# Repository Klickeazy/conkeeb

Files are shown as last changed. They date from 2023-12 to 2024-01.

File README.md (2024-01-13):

# Conkeeb - Split Keyboard

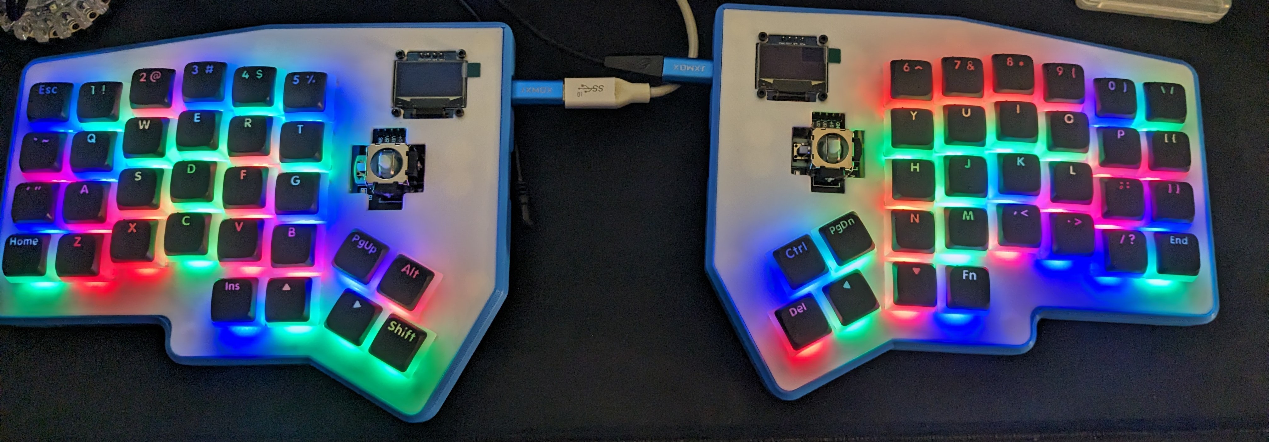
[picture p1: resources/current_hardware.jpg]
current keyboard


## Design and Fabrication
- Modified layout from ErgoDox on [KLE](http://www.keyboard-layout-editor.com/#/)
- Switch-plate template generated on [SwillKB](http://builder.swillkb.com/)
- CAD done on OnShape
- Printed on a modified Ender3Pro using a 0.6mm nozzle in PLA

## Bill of Materials
- 2 x Adafruit [NeoKey 5x6 Ortho Snap-Apart Mechanical Key Switches w/ NeoPixel - For MX Compatible Switches](https://www.adafruit.com/product/5157)
- 60 x MX socket compatible switches : Using [Gateron KS-9 RGB](https://a.co/d/2FaNAoF) for LEDs
- 50 x 1u keycaps compatible to switch stems : [Pudding Style XDA](https://a.co/d/bYV5bW5) for LEDs
- 2 x Joystick with breakout board [WMYCONGCONG Game Joystick](https://a.co/d/7XcAHXY)
- 2 x Display units [Hosyond 0.96 Inch OLED](https://a.co/d/dcp77Un)
- 2 x [USB-A breakout](https://a.co/d/6CouvCj) + 1 [USB-A Male to Male cable](https://a.co/d/9nUPYLn) : to connect the two halves of the keyboard - need 4 lines for UART, could look at alternate TRRS or USB-C connector choices
- 2 x [RPi-Pico](https://www.raspberrypi.com/products/raspberry-pi-pico/) for each of the halves - there are some spare GPIO pins - could add more hardware like an encoder or use a smaller one by sacrificing the joystick or display unit

- Fasteners **per KB half**
    - 4-6 x M3 6mm(H)x5mm(OD) heat-set inserts and 6mm socket-heads for the case and switch plate - holes dimensioned to allow for socket heads to sink into the base
    - 2 x M3 4mm (H)x5mm(OD) heat-set inserts and 4mm socket-heads for the USB-A breakout board
    - 2 x M2 4mm(H)x3.5mm(OD) heat-set inserts and 6mm screws for the Pico
    - 4 x M2 4mm socket-heads and nuts for the display unit - these screw heads are visible - pick whatever you think looks the best
    - optional :  3 x 2mm(H)x6mm(D) magnets for the foot and base

- [3D Printed parts](stl)
    - 1 each of switchplate and base L & R
    - optional foot L & R
    - Approximately 100g per base, 40g per switchplate and foot - tested with 0.6mm nozzle, 0.32mm layer height 25% adaptive cubic infill

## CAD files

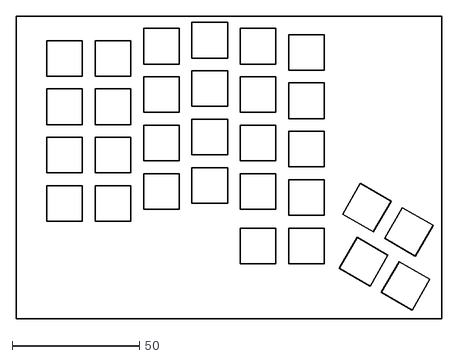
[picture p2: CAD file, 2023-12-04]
layout/V3/plate_gen.dxf
167.5 x 119.2

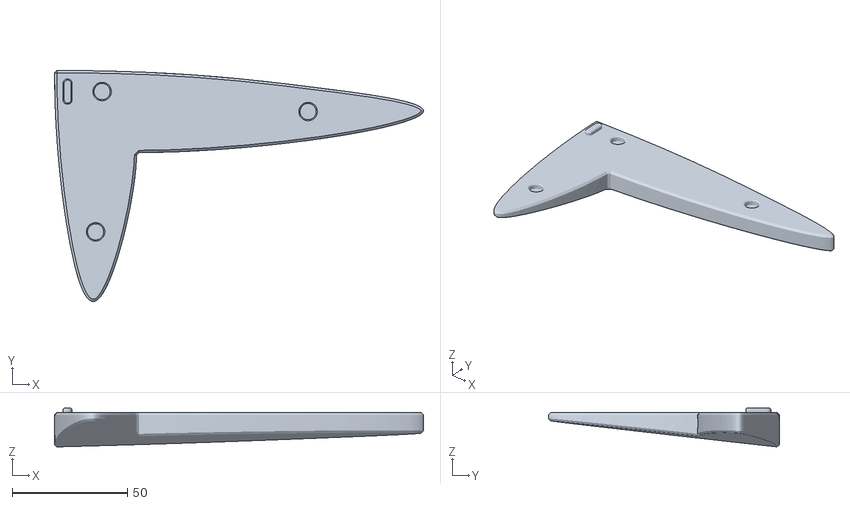
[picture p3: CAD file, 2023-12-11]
stl/FootR.stl
160.0 x 100.2 x 16.9

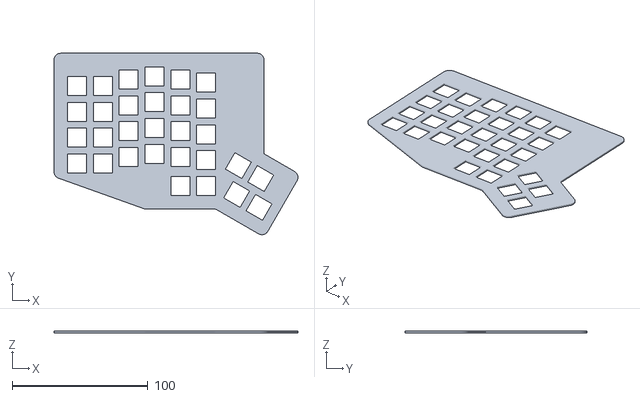
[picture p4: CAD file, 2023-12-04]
layout/V3/KeyPlateV3.stl
180.0 x 133.9 x 1.28

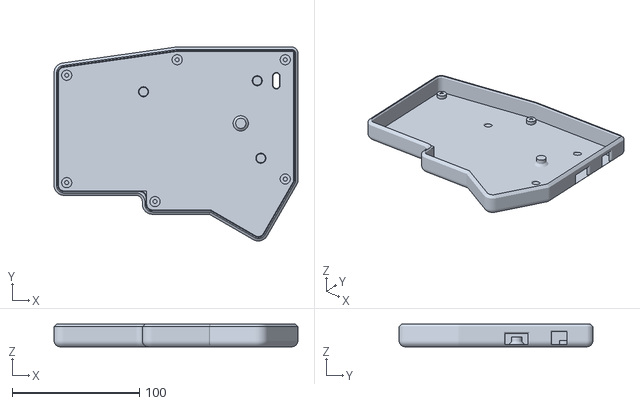
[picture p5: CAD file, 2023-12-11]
stl/BaseL.stl
191.6 x 152.3 x 17.8

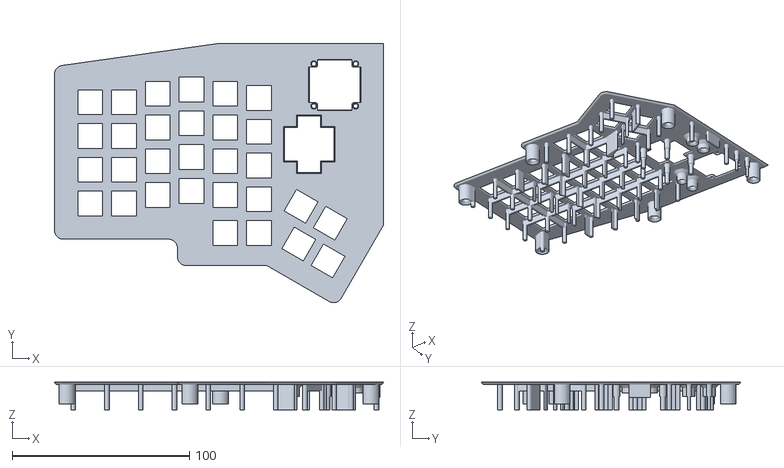
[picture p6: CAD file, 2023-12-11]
stl/SwitchPlateL.stl
185.6 x 146.3 x 15.8

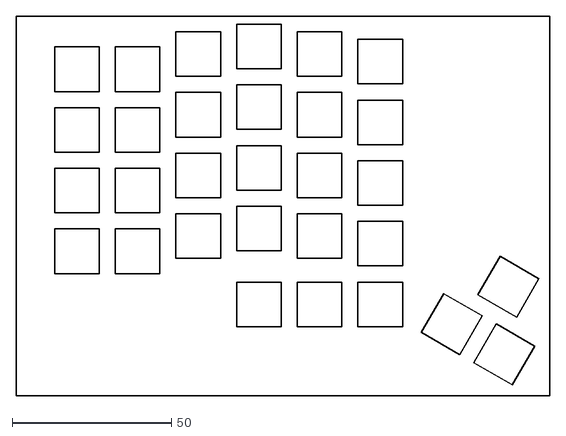
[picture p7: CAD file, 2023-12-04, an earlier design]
layout/V2/switch_plate.dxf
167.5 x 119.2

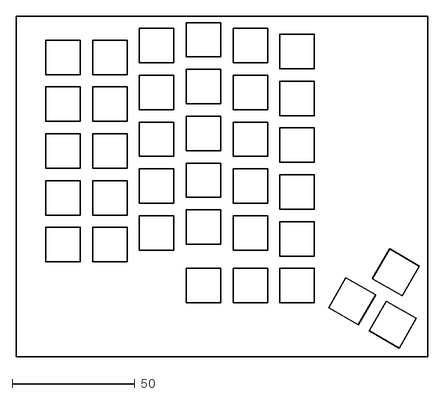
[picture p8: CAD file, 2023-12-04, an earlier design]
layout/V2/switch_plate_wFN.dxf
167.5 x 138.4

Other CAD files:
stl/FootL.stl
stl/SwitchPlateR.stl
stl/BaseR.stl

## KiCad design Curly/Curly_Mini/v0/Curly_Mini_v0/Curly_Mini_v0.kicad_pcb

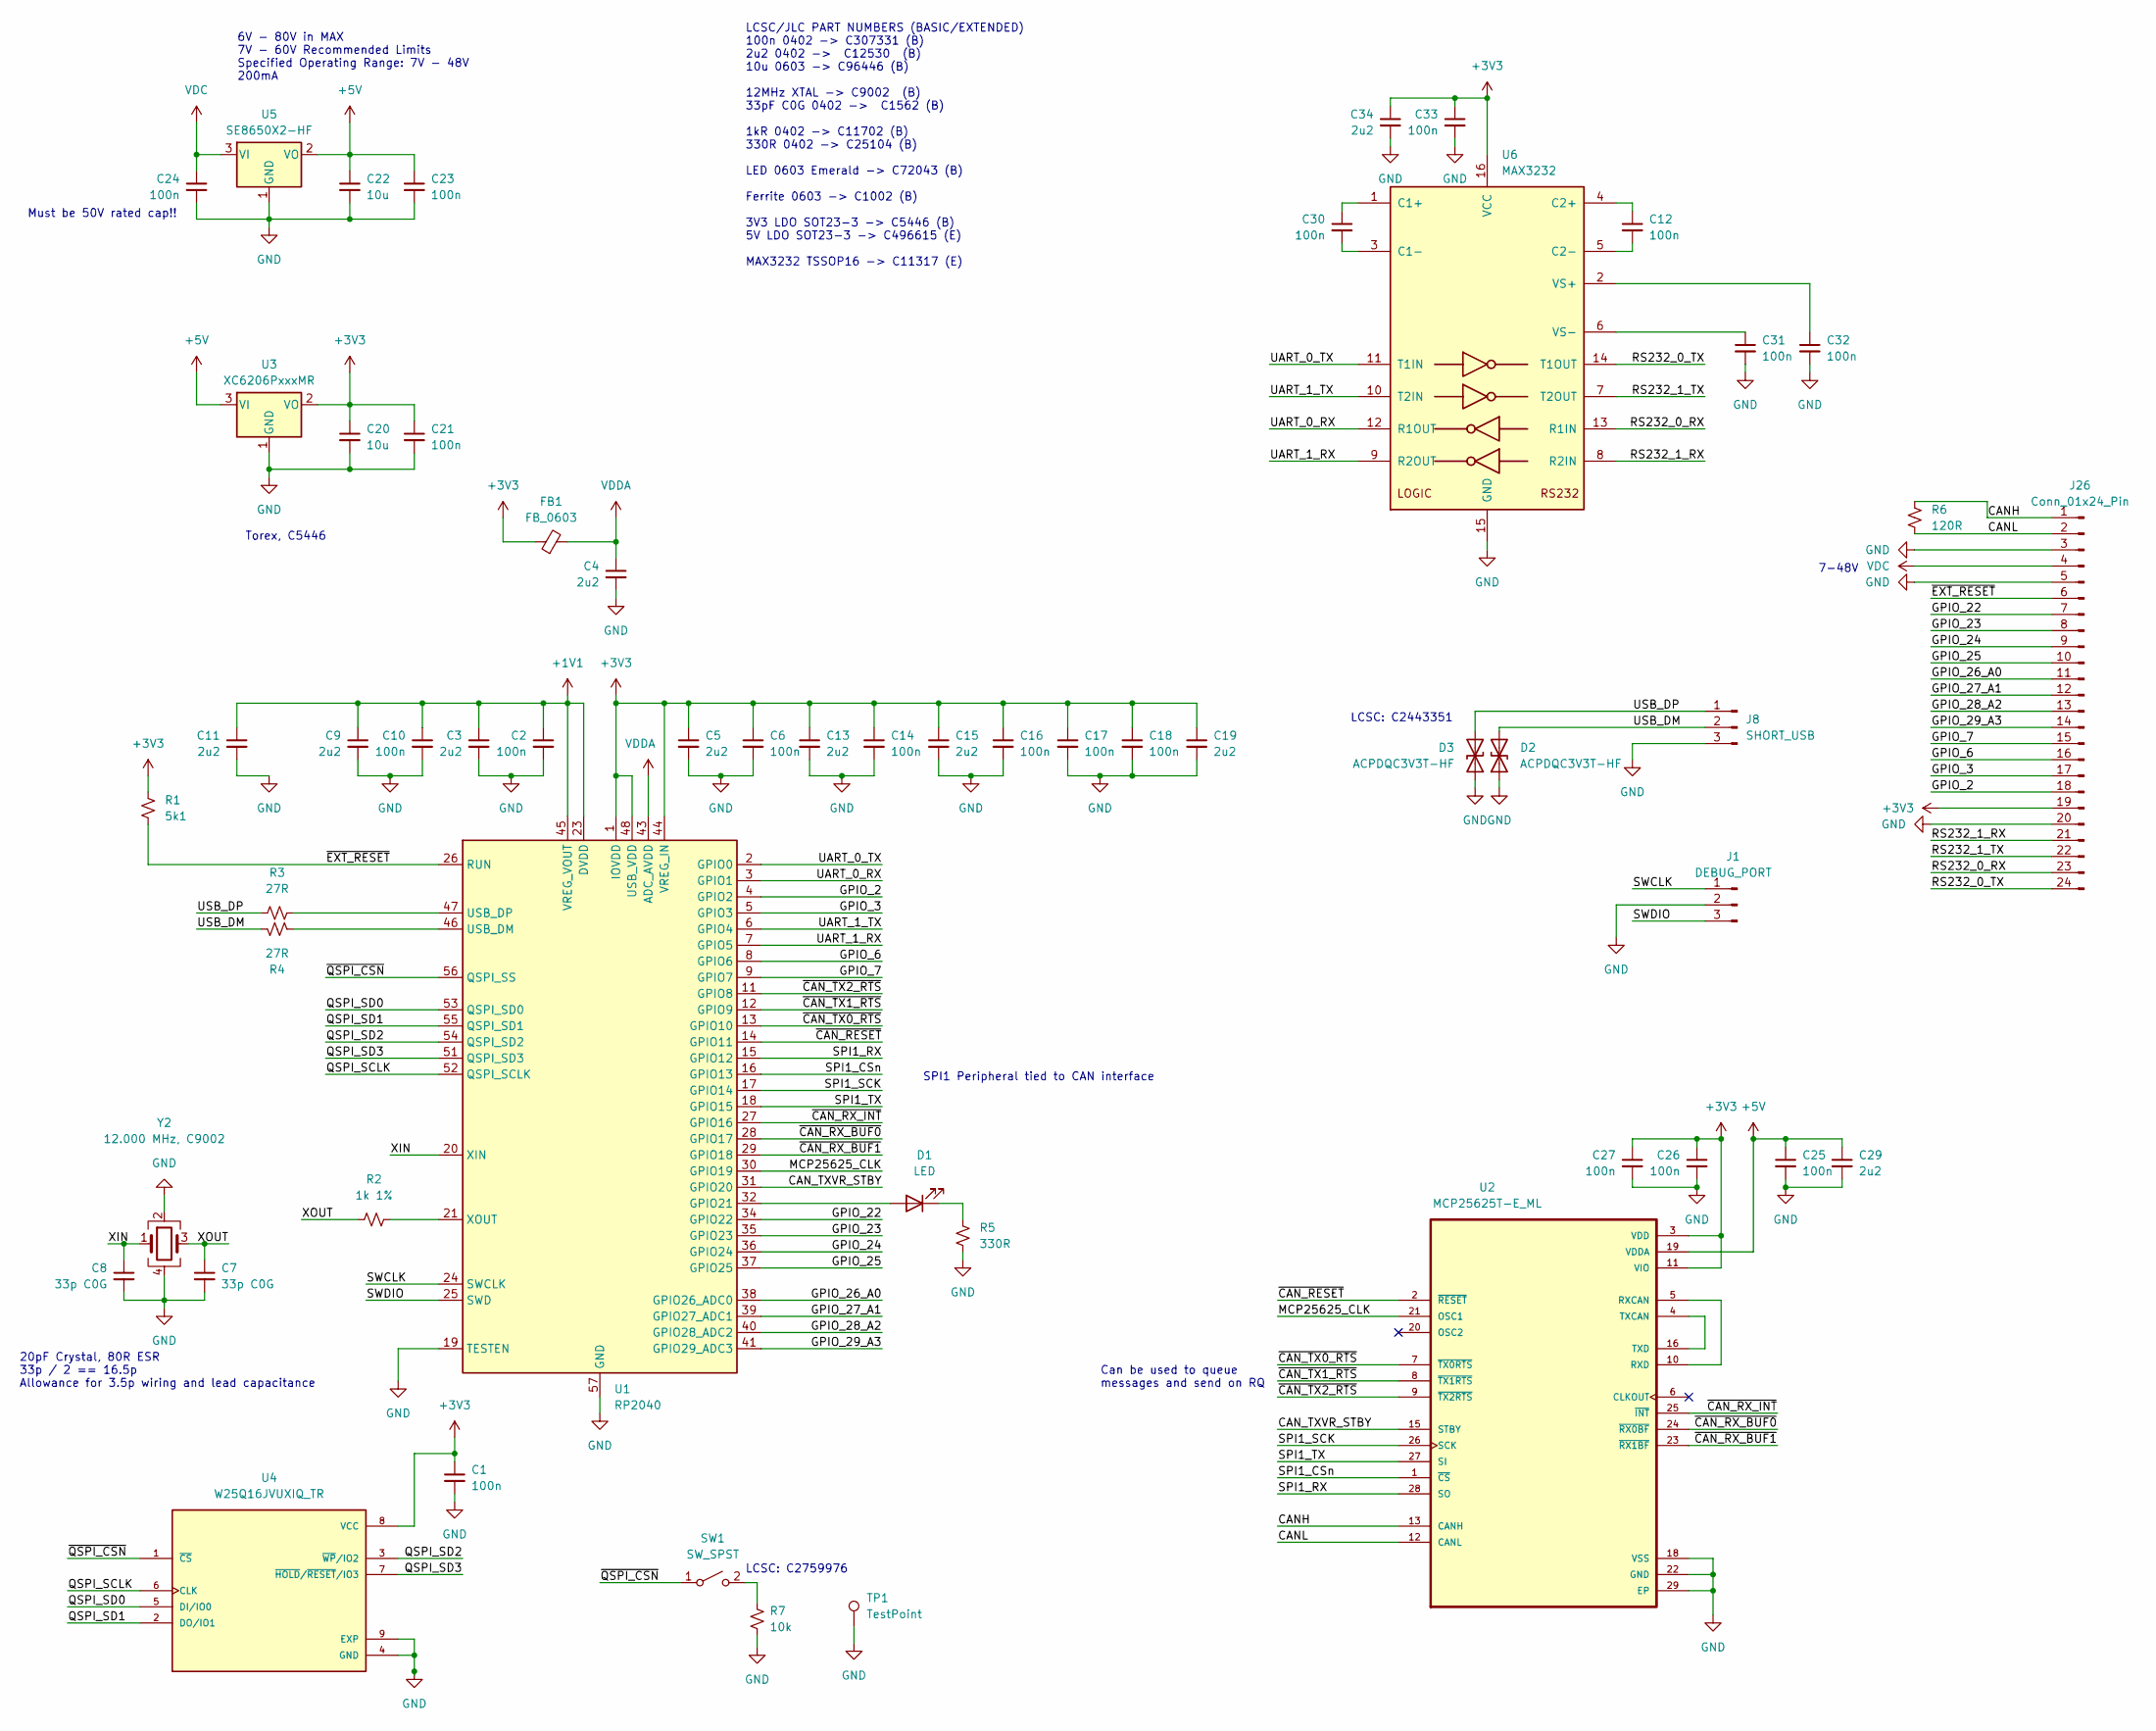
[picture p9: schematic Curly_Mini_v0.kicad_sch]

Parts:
C1, C2, C6, C10, C12, C14, C16, C17, C18, C21, C23, C24, C25, C26, C27, C30, C31, C32, C33: 100n; C_0402_1005Metric
C3, C4, C5, C9, C11, C13, C15, C19, C29, C34: 2u2; C_0402_1005Metric
C7, C8: 33p C0G; C_0402_1005Metric
C20, C22: 10u; C_0603_1608Metric
D1: LED; LED_0603_1608Metric
D2, D3: ACPDQC3V3T-HF; 0402C-SOD-923F
FB1: FB_0603; L_0603_1608Metric
J1: DEBUG_PORT; JST_SH_BM03B-SRSS-TB_1x03-1MP_P1.00mm_Vertical
J8: SHORT_USB; PinSocket_1x03_P2.54mm_Vertical
J26: Conn_01x24_Pin; ICDB_Curly_Edge_Conn
R1: 5k1; R_0402_1005Metric
R2: 1k 1%; R_0402_1005Metric
R3, R4: 27R; R_0402_1005Metric
R5: 330R; R_0402_1005Metric
R6: 120R; R_0805_2012Metric_Pad1.20x1.40mm_HandSolder
R7: 10k; R_0402_1005Metric
SW1: SW_SPST; TPS850 J14Q V SMTR LFS
TP1: TestPoint; TestPoint_Pad_D2.0mm
U1: RP2040; QFN-56-1EP_7x7mm_P0.4mm_EP3.2x3.2mm
U2: MCP25625T-E_ML; QFN65P600X600X100-29N; DIGI-KEY_PART_NUMBER MCP25625T-E/MLCT-ND
U3: XC6206PxxxMR; SOT-23-3
U4: W25Q16JVUXIQ_TR; IC_W25Q16JVUXIQ_TR; PARTREV H
U5: SE8650X2-HF; SOT-23-3
U6: MAX3232; TSSOP-16_4.4x5mm_P0.65mm
Y2: 12.000 MHz, C9002; Crystal_SMD_3225-4Pin_3.2x2.5mm

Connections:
+1V1: C2.1, C3.1, C9.1, C10.1, C11.1, U1.23 (DVDD), U1.45 (VREG_VOUT), U1.50 (DVDD)
+3V3: C1.1, C5.1, C6.1, C13.1, C14.1, C15.1, C16.1, C17.1, C18.1, C19.1, C20.1, C21.1, C26.1, C27.1, C33.1, C34.1, FB1.1, J26.19, R1.1, U1.1 (IOVDD), U1.10 (IOVDD), U1.22 (IOVDD), U1.33 (IOVDD), U1.42 (IOVDD), U1.44 (VREG_IN), U1.48 (USB_VDD), U1.49 (IOVDD), U2.3 (VDD), U2.11 (VIO), U3.2 (VO), U4.8 (VCC), U6.16 (VCC)
+5V: C22.1, C23.1, C25.1, C29.1, U2.19 (VDDA), U3.3 (VI), U5.2 (VO)
/CANH: J26.1, R6.1, U2.13 (CANH)
/CANL: J26.2, R6.2, U2.12 (CANL)
/CAN_TXVR_STBY: U1.31 (GPIO20), U2.15 (STBY)
/GPIO_2: J26.18, U1.4 (GPIO2)
/GPIO_3: J26.17, U1.5 (GPIO3)
/GPIO_6: J26.16, U1.8 (GPIO6)
/GPIO_7: J26.15, U1.9 (GPIO7)
/GPIO_22: J26.7, U1.34 (GPIO22)
/GPIO_23: J26.8, U1.35 (GPIO23)
/GPIO_24: J26.9, U1.36 (GPIO24)
/GPIO_25: J26.10, U1.37 (GPIO25)
/GPIO_26_A0: J26.11, U1.38 (GPIO26_ADC0)
/GPIO_27_A1: J26.12, U1.39 (GPIO27_ADC1)
/GPIO_28_A2: J26.13, U1.40 (GPIO28_ADC2)
/GPIO_29_A3: J26.14, U1.41 (GPIO29_ADC3)
/MCP25625_CLK: U1.30 (GPIO19), U2.21 (OSC1)
/QSPI_SCLK: U1.52 (QSPI_SCLK), U4.6 (CLK)
/QSPI_SD0: U1.53 (QSPI_SD0), U4.5 (DI/IO0)
/QSPI_SD1: U1.55 (QSPI_SD1), U4.2 (DO/IO1)
/QSPI_SD2: U1.54 (QSPI_SD2), U4.3 (~WP/IO2)
/QSPI_SD3: U1.51 (QSPI_SD3), U4.7 (~HOLD/~RESET/IO3)
/RS232_0_RX: J26.23, U6.13 (R1IN)
/RS232_0_TX: J26.24, U6.14 (T1OUT)
/RS232_1_RX: J26.21, U6.8 (R2IN)
/RS232_1_TX: J26.22, U6.7 (T2OUT)
/SPI1_CSn: U1.16 (GPIO13), U2.1 (~CS)
/SPI1_RX: U1.15 (GPIO12), U2.28 (SO)
/SPI1_SCK: U1.17 (GPIO14), U2.26 (SCK)
/SPI1_TX: U1.18 (GPIO15), U2.27 (SI)
/SWCLK: J1.1, U1.24 (SWCLK)
/SWDIO: J1.3, U1.25 (SWD)
/UART_0_RX: U1.3 (GPIO1), U6.12 (R1OUT)
/UART_0_TX: U1.2 (GPIO0), U6.11 (T1IN)
/UART_1_RX: U1.7 (GPIO5), U6.9 (R2OUT)
/UART_1_TX: U1.6 (GPIO4), U6.10 (T2IN)
/USB_DM: D2.2 (A2), J8.2, R4.1
/USB_DP: D3.2 (A2), J8.1, R3.1
/XIN: C8.1, U1.20 (XIN), Y2.1
/XOUT: C7.1, R2.1, Y2.3
/~CAN_RESET: U1.14 (GPIO11), U2.2 (~RESET)
/~CAN_RX_BUF0: U1.28 (GPIO17), U2.24 (~RX0BF)
/~CAN_RX_BUF1: U1.29 (GPIO18), U2.23 (~RX1BF)
/~CAN_RX_INT: U1.27 (GPIO16), U2.25 (~INT)
/~CAN_TX0_RTS: U1.13 (GPIO10), U2.7 (~TX0RTS)
/~CAN_TX1_RTS: U1.12 (GPIO9), U2.8 (~TX1RTS)
/~CAN_TX2_RTS: U1.11 (GPIO8), U2.9 (~TX2RTS)
/~EXT_RESET: J26.6, R1.2, U1.26 (RUN)
/~QSPI_CSN: SW1.1 (A), U1.56 (QSPI_SS), U4.1 (~CS)
GND: C1.2, C2.2, C3.2, C4.2, C5.2, C6.2, C7.2, C8.2, C9.2, C10.2, C11.2, C13.2, C14.2, C15.2, C16.2, C17.2, C18.2, C19.2, C20.2, C21.2, C22.2, C23.2, C24.2, C25.2, C26.2, C27.2, C29.2, C31.2, C32.2, C33.2, C34.2, D2.1 (A1), D3.1 (A1), J1.2, J8.3, J26.3, J26.5, J26.20, R5.2, R7.2, TP1.1, U1.19 (TESTEN), U1.57 (GND), U2.18 (VSS), U2.22 (GND), U2.29 (EP), U3.1 (GND), U4.4 (GND), U4.9 (EXP), U5.1 (GND), U6.15 (GND), Y2.2, Y2.4
unnamed: D1.2 (A), U1.32 (GPIO21)
unnamed: D1.1 (K), R5.1
unnamed: R7.1, SW1.2 (B)
unnamed: R4.2, U1.46 (USB_DM)
unnamed: R3.2, U1.47 (USB_DP)
unnamed: R2.2, U1.21 (XOUT)
unnamed: U2.5 (RXCAN), U2.10 (RXD)
unnamed: U2.4 (TXCAN), U2.16 (TXD)
unnamed: C30.1, U6.1 (C1+)
unnamed: C30.2, U6.3 (C1-)
unnamed: C12.1, U6.4 (C2+)
unnamed: C12.2, U6.5 (C2-)
unnamed: C32.1, U6.2 (VS+)
unnamed: C31.1, U6.6 (VS-)
VDC: C24.1, J26.4, U5.3 (VI)
VDDA: C4.1, FB1.2, U1.43 (ADC_AVDD)

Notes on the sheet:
Must be 50V rated cap!!
20pF Crystal, 80R ESR 33p / 2 == 16.5p Allowance for 3.5p wiring and lead capacitance
Torex, C5446
SPI1 Peripheral tied to CAN interface
Can be used to queue messages and send on RQ
LCSC: C2443351
LCSC/JLC PART NUMBERS (BASIC/EXTENDED) 100n 0402 -> C307331 (B) 2u2 0402 -> C12530 (B) 10u 0603 -> C96446 (B) 12MHz XTAL -> C9002 (B) 33pF C0G 0402 -> C1562 (B) 1kR 0402 -> C11702 (B) 330R 0402 -> C25104 (B) LED 0603 Emerald -> C72043 (B) Ferrite 0603 -> C1002 (B) 3V3 LDO SOT23-3 -> C5446 (B) 5V LD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
LCSC: C2759976
6V - 80V in MAX 7V - 60V Recommended Limits Specified Operating Range: 7V - 48V 200mA
7-48V

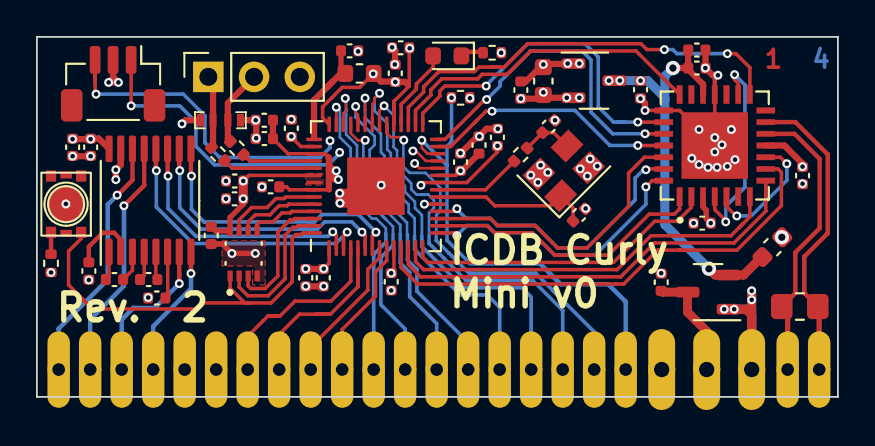
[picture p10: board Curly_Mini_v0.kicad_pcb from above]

Board: 4 copper layers, 44.5 x 20.0 mm, 56 parts (0 on the bottom side), 68 nets.

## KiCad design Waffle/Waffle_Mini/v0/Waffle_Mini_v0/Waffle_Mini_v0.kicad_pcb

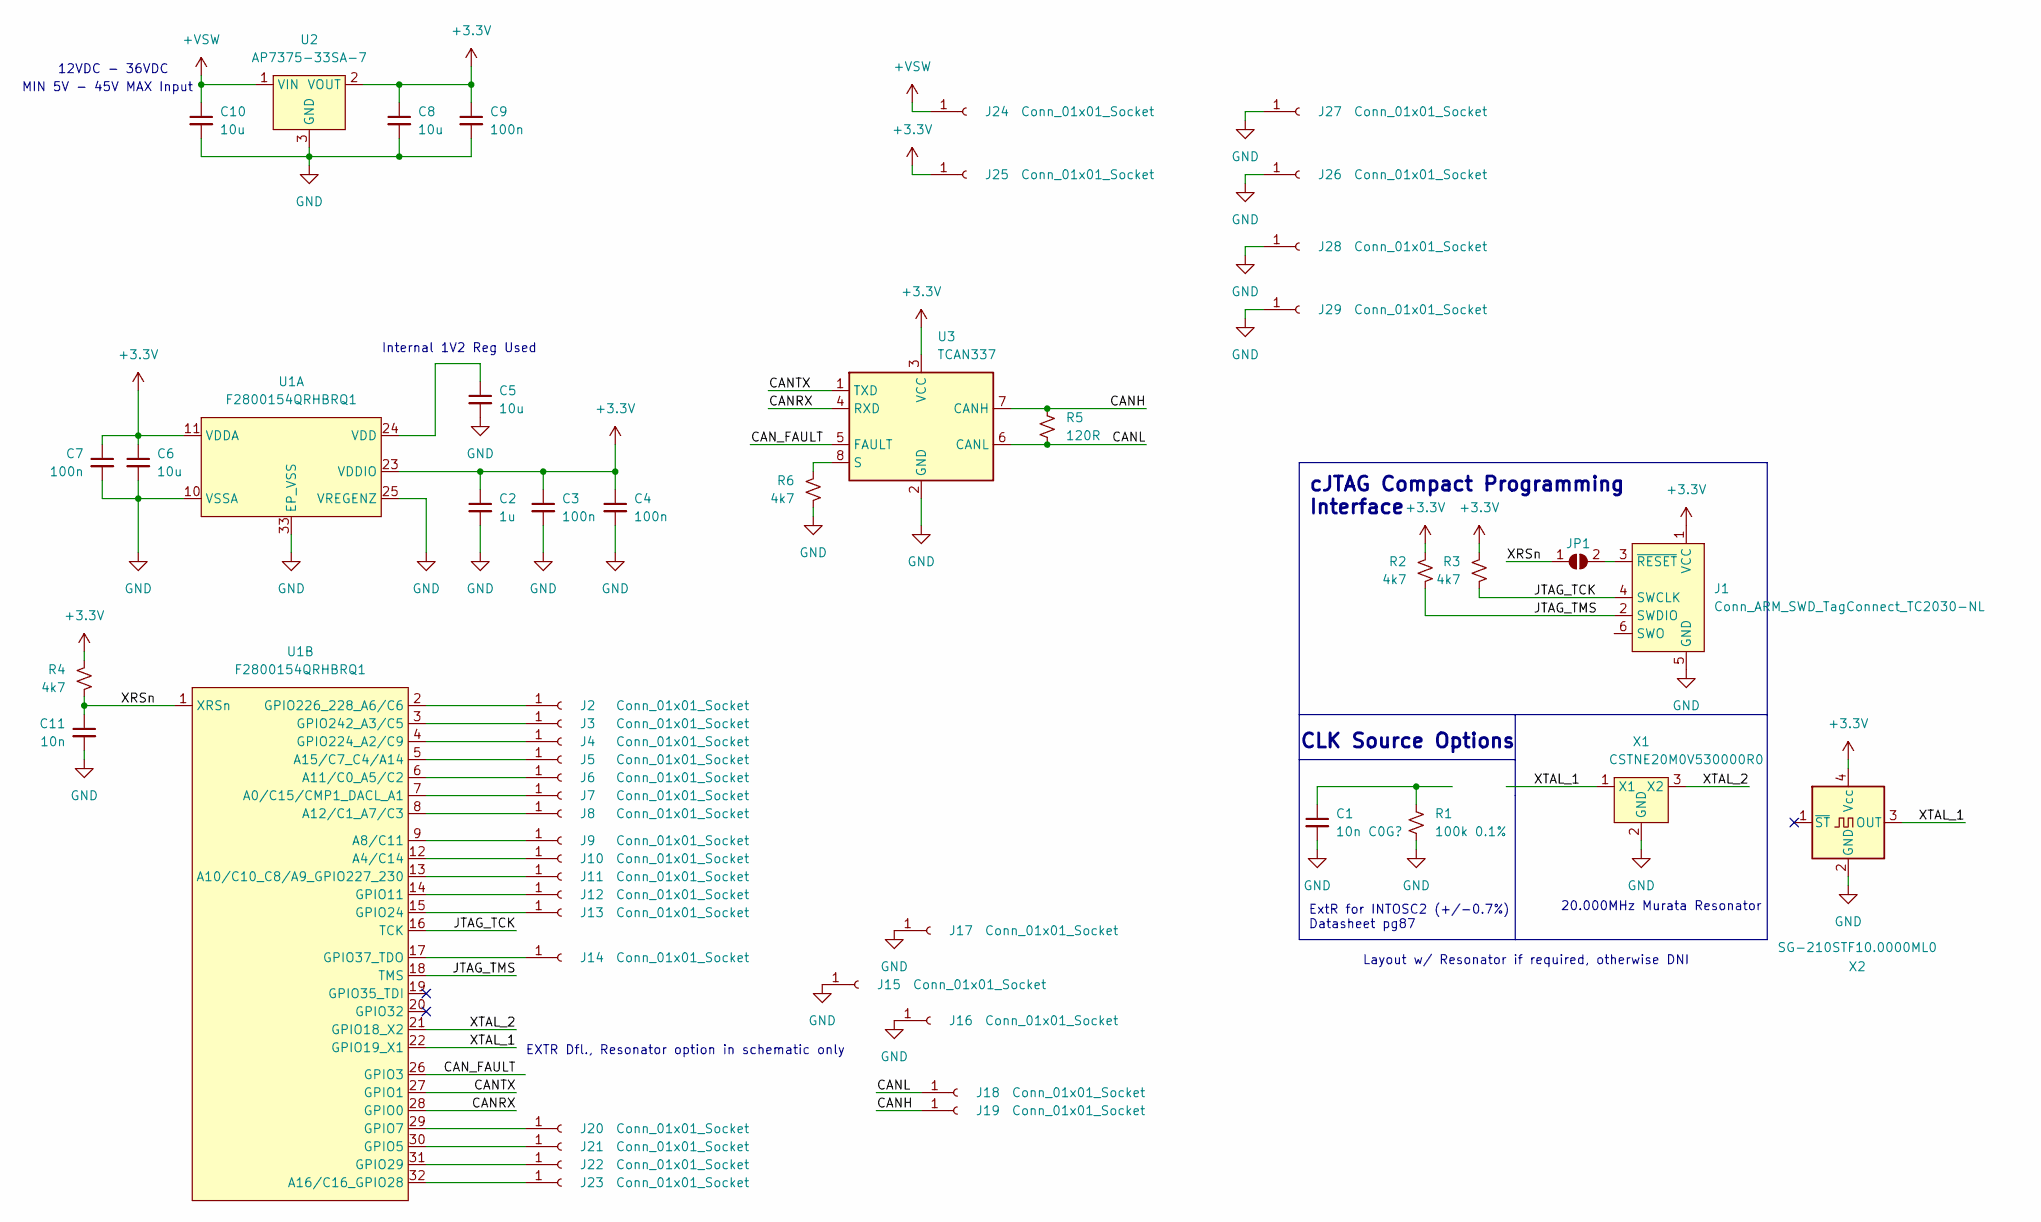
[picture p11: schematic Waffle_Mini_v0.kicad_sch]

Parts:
C1: 10n C0G?; C_0603_1608Metric
C2: 1u; C_0805_2012Metric
C3, C4, C7, C9: 100n; C_0603_1608Metric
C5, C6, C8: 10u; C_0805_2012Metric
C10: 10u; C_1210_3225Metric
C11: 10n; C_0603_1608Metric
J1: Conn_ARM_SWD_TagConnect_TC2030-NL; Tag-Connect_TC2030-IDC-NL_2x03_P1.27mm_Vertical
J2, J3, J4, J5, J6, J7, J8, J9, J10, J11, J12, J13, J14, J15, J16, J17, J18, J19, J20, J21, J22, J23, J24, J25, J26, J27, J28, J29: Conn_01x01_Socket; ICDB_Castellated_Pad
JP1: SolderJumper_2_Open; SolderJumper-2_P1.3mm_Open_TrianglePad1.0x1.5mm
R1: 100k 0.1%; R_0603_1608Metric
R2, R3, R4, R6: 4k7; R_0603_1608Metric
R5: 120R; R_0805_2012Metric
U1: F2800154QRHBRQ1; VQFN-32-1EP_5x5mm_P0.5mm_EP3.15x3.15mm
U2: AP7375-33SA-7; SOT-23-3
U3: TCAN337; SOT-23-8
X1: CSTNE20M0V530000R0; CSTNE_Murata_Resonator
X2: SG-210STF10.0000ML0; Oscillator_SMD_SeikoEpson_SG210-4Pin_2.5x2.0mm

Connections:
+3.3V: C2.1, C3.1, C4.1, C6.1, C7.1, C8.1, C9.1, J1.1 (VCC), J25.1, R2.1, R3.1, R4.1, U1.11 (VDDA), U1.23 (VDDIO), U2.2 (VOUT), U3.3 (VCC), X2.4 (Vcc)
+VSW: C10.1, J24.1, U2.1 (VIN)
/CANH: J19.1, R5.1, U3.7 (CANH)
/CANL: J18.1, R5.2, U3.6 (CANL)
/CANRX: U1.28 (GPIO0), U3.4 (RXD)
/CANTX: U1.27 (GPIO1), U3.1 (TXD)
/CAN_FAULT: U1.26 (GPIO3), U3.5 (FAULT)
/JTAG_TCK: J1.4 (SWCLK), R3.2, U1.16 (TCK)
/JTAG_TMS: J1.2 (SWDIO), R2.2, U1.18 (TMS)
/XRSn: C11.1, JP1.1 (A), R4.2, U1.1 (XRSn)
/XTAL_1: U1.22 (GPIO19_X1), X1.1 (X1), X2.3 (OUT)
/XTAL_2: U1.21 (GPIO18_X2), X1.3 (X2)
GND: C1.2, C2.2, C3.2, C4.2, C5.2, C6.2, C7.2, C8.2, C9.2, C10.2, C11.2, J1.5 (GND), J15.1, J16.1, J17.1, J26.1, J27.1, J28.1, J29.1, R1.2, R6.2, U1.10 (VSSA), U1.25 (VREGENZ), U1.33 (EP_VSS), U2.3 (GND), U3.2 (GND), X1.2 (GND), X2.2 (GND)
unnamed: C1.1, R1.1
unnamed: J1.3 (~RESET), JP1.2 (B)
unnamed: J2.1, U1.2 (GPIO226_228_A6/C6)
unnamed: J3.1, U1.3 (GPIO242_A3/C5)
unnamed: J4.1, U1.4 (GPIO224_A2/C9)
unnamed: J5.1, U1.5 (A15/C7_C4/A14)
unnamed: J6.1, U1.6 (A11/C0_A5/C2)
unnamed: J7.1, U1.7 (A0/C15/CMP1_DACL_A1)
unnamed: J8.1, U1.8 (A12/C1_A7/C3)
unnamed: J9.1, U1.9 (A8/C11)
unnamed: J10.1, U1.12 (A4/C14)
unnamed: J11.1, U1.13 (A10/C10_C8/A9_GPIO227_230)
unnamed: J12.1, U1.14 (GPIO11)
unnamed: J13.1, U1.15 (GPIO24)
unnamed: J14.1, U1.17 (GPIO37_TDO)
unnamed: J20.1, U1.29 (GPIO7)
unnamed: J21.1, U1.30 (GPIO5)
unnamed: J22.1, U1.31 (GPIO29)
unnamed: J23.1, U1.32 (A16/C16_GPIO28)
unnamed: C5.1, U1.24 (VDD)
unnamed: R6.1, U3.8 (S)

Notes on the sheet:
ExtR for INTOSC2 (+/-0.7%) Datasheet pg87
EXTR Dfl., Resonator option in schematic only
CLK Source Options
Layout w/ Resonator if required, otherwise DNI
12VDC - 36VDC
Internal 1V2 Reg Used
cJTAG Compact Programming Interface
MIN 5V - 45V MAX Input
20.000MHz Murata Resonator

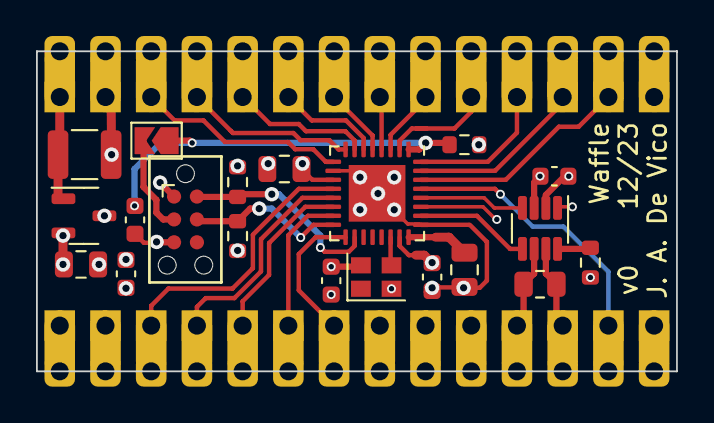
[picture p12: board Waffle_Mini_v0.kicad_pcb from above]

Board: 4 copper layers, 35.6 x 17.8 mm, 48 parts (0 on the bottom side), 32 nets.

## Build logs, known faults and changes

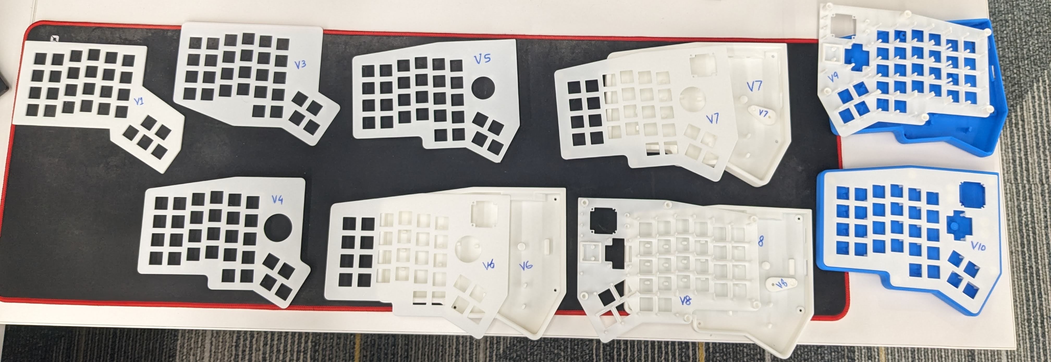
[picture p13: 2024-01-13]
resources/version_history.jpg

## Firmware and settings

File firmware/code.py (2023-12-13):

import board

from kmk.kmk_keyboard import KMKKeyboard
from kmk.keys import KC
from kmk.scanners import DiodeOrientation

from kb import data_pin
from kmk.modules.split import Split, SplitSide
from storage import getmount

from kmk.modules.layes import Layers
keyboard.modules.append(Layers())

keyboard = KMKKeyboard()

side = SplitSide.RIGHT if str(getmount('/').label)[-1] == 'R' else SplitSide.LEFT

split = Split(split_side=SplitSide.LEFT)
keyboard.modules.append(split)

split = Split( # NAME DRIVES AS CIRCUITPYL and CIRCUITPYR respectively
    split_flip=True,  # If both halves are the same, but flipped, set this True - check wiring
    split_type=SplitType.UART,  # Defaults to UART
    split_target_left=True,  # Assumes that left will be the one on USB. Set to False if it will be the right
    uart_interval=20,  # Sets the uarts delay. Lower numbers draw more power
    data_pin=board.GP1,  # The primary data pin to talk to the secondary device with
    data_pin2=board.GP0,  # Second uart pin to allow 2 way communication
    uart_flip=True,  # Reverses the RX and TX pins if both are provided
    use_pio=False,  # Use RP2040 PIO implementation of UART. Required if you want to use other pins than RX/TX
)


side = SplitSide.RIGHT if str(getmount('/').label)[-1] == 'R' else SplitSide.LEFT

if side == SplitSide.RIGHT:
    keyboard.col_pins = (board.GP2, board.GP3, board.GP4, board.GP5, board.GP6, board.GP7)
    keyboard.row_pins = (board.GP9, board.GP10, board.GP11, board.GP12, board.GP13)
    # keyboard.data_pin = 
    # keyboard.diode_orientation = ...
else:
    keyboard.col_pins = (board.GP7, board.GP6, board.GP5, board.GP4, board.GP3, board.GP2)
    keyboard.row_pins = (board.GP9, board.GP10, board.GP11, board.GP12, board.GP13)

keyboard.diode_orientation = DiodeOrientation.ROW2COL

# keyboard.col_pins = (board.GP7, board.GP6, board.GP5, board.GP4, board.GP3, board.GP2)
# keyboard.row_pins = (board.GP9, board.GP10, board.GP11, board.GP12, board.GP13)
# keyboard.diode_orientation = DiodeOrientation.COL2ROW

# thumb-cluster on left half : Row 5, Col (0,1), Col(2,3)
# thumb-cluster on right half : Row 5, Col (0,1), Col(2,3)

# [ 0 1 2 3 4 5
#  6 7 8 9 10 11
#  12 13 14 15 16 17
#  18 19 20 21 22 23    24 25
#              28 29    26 27]

# http://kmkfw.io/docs/keycodes/

keyboard.keymap = [
    [   #0
        KC.ESC, KC.N1, KC.N2, KC.N3, KC.N4, KC.N5, KC.N6, KC.N7, KC.N8, KC.N9, KC.N0, KC.GRV,
        KC.GRAVE, KC.Q, KC.W, KC.E, KC.R, KC.T, KC.Y, KC.U, KC.I, KC.O, KC.P, KC.BSLS,
        KC.QUOTE, KC.A, KC.S, KC.D, KC.F, KC.G, KC.H, KC.J, KC.K, KC.L, KC.SCLN, KC.RSFT,
        KC.HOME, KC.Z, KC.X, KC.C, KC.V, KC.B, KC.N, KC.M, KC.COMM, KC.DOT, KC.SLSH, KC.RCTL,
        None, KC.LALT, KC.SPC, KC.LSHIFT, None, KC.TO(1), None, KC.FN, None, None, None, None
    ],
    [   #1 - Function Layer pass through
        KC.F1, KC.F2, KC.F3, KC.F4, KC.F5, KC.F6, KC.F7, KC.F8, KC.F9, KC.F10, KC.F11, KC.F12,
        None, None, None, None, None, None, None, None, None, None, None, None,
        None, None, None, None, None, None, None, None, None, None, None, None,
        None, None, None, None, None, None, None, None, None, None, None, None,
        None, None, None, None, None, None, None, None, None, None, None, None,
    ]
]


if __name__ == '__main__':
    keyboard.go()

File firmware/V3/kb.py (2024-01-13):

import board

from kmk.kmk_keyboard import KMKKeyboard as _KMKKeyboard
from kmk.scanners import DiodeOrientation

from storage import getmount

class KMKKeyboard(_KMKKeyboard):
    
    split_check = str(getmount('/').label)[-1]
    
    if split_check == 'L':
        col_pins = (board.GP7, board.GP6, board.GP5, board.GP4, board.GP3, board.GP2)
    else:
        col_pins = (board.GP2, board.GP3, board.GP4, board.GP5, board.GP6, board.GP7)

    row_pins = (board.GP9, board.GP10, board.GP11, board.GP12, board.GP13)

    diode_orientation = DiodeOrientation.ROW2COL

    led_pin = board.GP8
    led_count = 30

    data_pin_TX = board.GP0
    data_pin_RX = board.GP1
    
    SLC = board.GP19
    SDA = board.GP18
    
    js_x = board.GP26
    js_y = board.GP25
    js_switch = board.GP22
    
    coord_mapping = [
        0,  1,  2,  3,  4,  5,      30, 31, 32, 33, 34, 35,
        6,  7,  8,  9,  10, 11,     36, 37, 38, 39, 40, 41,
        12, 13, 14, 15, 16, 17,     42, 43, 44, 45, 46, 47,
        18, 19, 20, 21, 22, 23,     48, 49, 50, 51, 52, 53,
        24, 25, 26, 27, 28, 29,     54, 55, 56, 57, 58, 59
    ]

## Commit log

2023-12-04 KLE - key placement update
    V1 - V3 of Keyboard Layout Editor
    [Connectors_V1.kicad_pcb, Connectors_V1.kicad_sch, KeyPlateV3.stl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]
2023-12-11 STL update
    [BaseL.stl, BaseR.stl, FootL.stl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]
2023-12-13 work dump
    need to define kb.py and identify datapins
    scanners for joystick as a mix of potentiometers and extra button
